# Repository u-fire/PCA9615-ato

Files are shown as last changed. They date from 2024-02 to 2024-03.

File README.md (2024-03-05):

# PCA9615

📒 [Datasheet](https://www.nxp.com/docs/en/data-sheet/PCA9615.pdf)

This repository is an [atopile](https://atopile.io/) module for the PCA9615, 2-channel multipoint Fast-mode differential I2C-bus. In other words, it lets
you use I2C like you might use MODBUS, ie. over long wires and through noisy environments. 

## 🏁 Get started
### Installation
From inside a project directory terminal: `ato install PCA9615-ato`

### Code
```ato
from "pca9615/elec/src/pca9615.ato" import PCA9615
from "generics/interfaces.ato" import DiffPair, Power, I2C, GPIO

module Test:
    # define virtual buses, connect these to physical components/pins
    power = new Power
    d_sda = new DiffPair
    d_scl = new DiffPair
    i2c = new I2C
    power_a_2v3_5v5 = new Power
    power_b_3v0_5v5 = new Power
    differential_side_power = new Power
    en = new GPIO

    # define the PCA9615
    pca9615 = new PCA9615

    # PCA9615 enable pin is driven high be an internal pullup
    # to disable chip, drive low
    en ~ pca9615.en

    # connect power to normal I2C side
    power_a_2v3_5v5 ~ pca9615.power_a_2v3_5v5

    # differential power can be seperate or the same as the I2C side
    pca9615.power_b_3v0_5v5 ~ power_a_2v3_5v5
    # - or -
    pca9615.power_b_3v0_5v5 ~ differential_side_power

    # normal I2C connection
    i2c ~ pca9615.i2c

    # differential pairs
    d_sda ~ pca9615.d_sda
    d_scl ~ pca9615.d_scl
```

## 🤔 Design Considerations
- d_sda and d_scl must be routed as differential pairs (`6` in KiCAD PCB Editor)
- power on the I2C side can be separate from the differential side, common grounds are not required
- the I2C side can accept between 2.3 - 5.5 volts
- the differential side can accept 3.0 - 5.5 volts
- an RJ45 connector and CAT6 cable work well for making the connections

## 🔌 Connections

|MCU | | MCU PCA9615 | |Sensor PCA9615 | | Sensor |
|---: |-: |---: |:-: |:--- |:-: | :-|
|  | | MCU PCA9615.d_SDA 🟩|~ |🟩 PCA9615.d_SDA|~ | 
| | | MCU PCA9615.d_SCL 🟪|~ |🟪 PCA9615.d_SCL|~
| MCU.SDA 🟨 |~ | 🟨 PCA9615.SDA 🟨| |🟨 PCA9615.SDA|~ |🟨 Sensor.SDA
| MCU.SCL 🟦 |~ | 🟦 PCA9615.SCL 🟦| |🟦 PCA9615.SCL|~ |🟦 Sensor.SCL
| *MCU.VCC* 🟥 | ~| 🟥 *PCA9615.VCC* 🟥 |*(optional)*|🟥 *PCA9615.VCC*|~ | 🟥 *Sensor.VCC*
|**MCU.GND**⬛ |~ | ⬛ **PCA9615.GND** ⬛|*(optional)*|⬛ **PCA9615.GND**|~|⬛ **Sensor.GND**

## ⚡ Programming
Once connected, the sensor (or just the other side) appear as a normal I2C device to the host. Nothing special needs to be done.

## 🙏 Contributing
This design is intended to be a community best-effort at a minimal circuit combining:
- datasheet reference design
- readily available components
- modular and reusable layout

You are greatly encouraged to contribute or discuss any improvements here so that everyone may benefit. 

## License
[CERN-OHL-P v2](https:/cern.ch/cern-ohl)

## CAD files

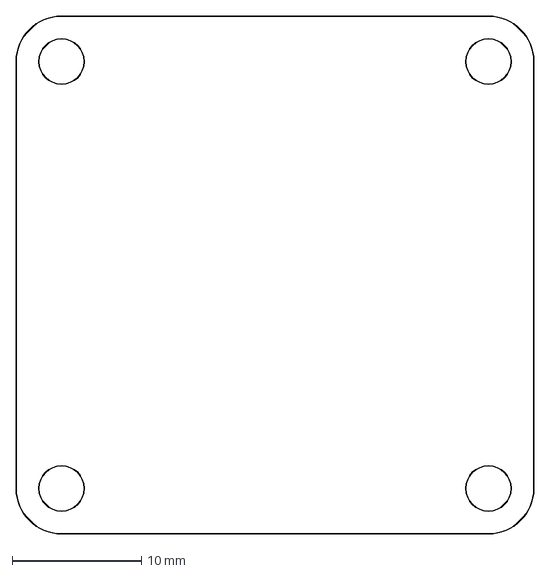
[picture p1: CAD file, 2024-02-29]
mech/template_outline.dxf
40.0 x 40.0 mm

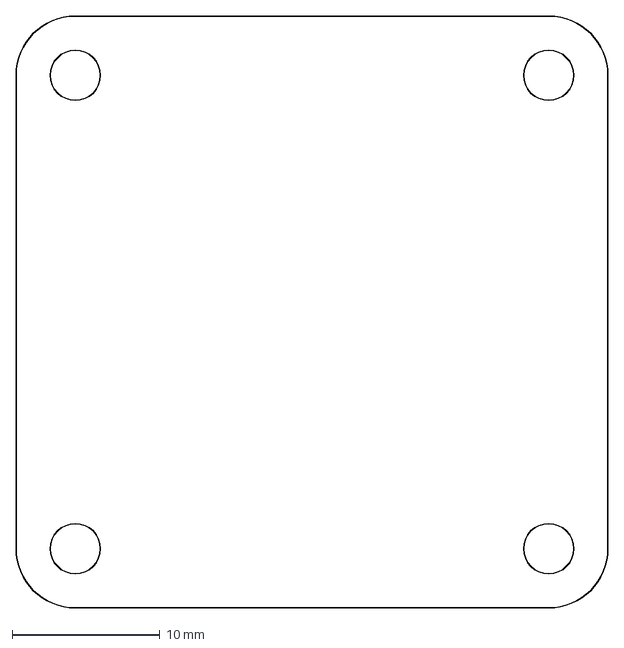
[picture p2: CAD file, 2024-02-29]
mech/template_40x40.dxf
40.0 x 40.0 mm

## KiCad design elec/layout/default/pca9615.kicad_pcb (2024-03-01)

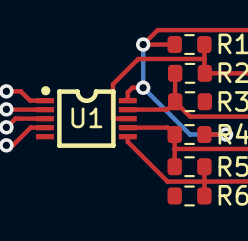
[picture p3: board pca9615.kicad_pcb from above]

Board: 2 copper layers, 7 parts (0 on the bottom side), 6 nets.

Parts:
R1, R3, R4, R6: Chip Resistor - Surface Mount 300Ohms ±5% 1/10W 0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; R0603
R2, R5: Chip Resistor - Surface Mount 100Ohms ±5% 1/10W 0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; R0603
U1: TSSOP-10_L3.0-W3.0-P0.50-LS4.9-BL

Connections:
dsclm: R5.2, R6.1, U1.6
dsclp: R4.2, R5.1, U1.7
dsdam: R2.2, R3.1, U1.9
dsdap: R1.2, R2.1, U1.8
gnd: R3.2, R6.2, U1.5
vdd_b_: R1.1, R4.1, U1.10
